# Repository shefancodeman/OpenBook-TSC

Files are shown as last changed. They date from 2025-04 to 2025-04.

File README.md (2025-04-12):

# TSC Openbook
 Un eBook reader format din PCB, carcasa, baterie si display, creat in AutoDesk Fusion. Fiecare component e asezat pe pcb pentru a intra corespunzator in carcasa.  
PCB-ul include:
- Battery Charge Level  
- E-Paper Display Header  
- E-Paper Drive Circuit  
- Environmental Sensor BME688  
- EPD Power  
- ESP32 C6  
- External NOR Flash 64MB  
- LDO Voltage Regulator  
- Li-Po Battery Charging Controller  
- Qwiic / Stemma QT  
- RTC Module DS3231SN  
- SD Card  
- SPI ESD Protection Lines  
- Test Pads  
- USB C connector & ESD protection  
- Voltage Supervisor + Reset & Boot / IO Button  

## BOM
| Component | Websites | Datasheet |
|---|---|---|
| ESP32-C6-WROOM-1-N8 | [Mouser](https://eu.mouser.com/ProductDetail/Espressif-Systems/ESP32-C6-WROOM-1U-N8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) | [Datasheet](https://eu.mouser.com/datasheet/2/891/Espressif_Systems_7_11_2023_esp32_c6_wroom_1_wroom-3236277.pdf) |
| USB4110-GF-A | [Mouser](https://eu.mouser.com/ProductDetail/Same-Sky/UJC-H-G-SMT-2-P6-TR?qs=IKkN%2F947nfApFV8T6rOqww%3D%3D) | [Datasheet](https://eu.mouser.com/datasheet/2/1628/ujc_h_g_smt_2_p6_tr-3511211.pdf) |
| USBLC6-2SC6Y | [Mouser](https://eu.mouser.com/ProductDetail/STMicroelectronics/USBLC6-2SC6Y?qs=gNDSiZmRJS%2FOgDexvXkdow%3D%3D) | [Datasheet](https://eu.mouser.com/datasheet/2/389/usblc6_2sc6y-1852505.pdf) |
| DMG2305UX-7 | [Mouser](https://eu.mouser.com/ProductDetail/Diodes-Incorporated/DMG2305UX-7?qs=L1DZKBg7t5F%2FNBHrjfxC%252Bg%3D%3D) | [Datasheet](https://www.diodes.com/assets/Datasheets/DMG2305UX.pdf) |
| SD0805S020S1R0 | [Mouser](https://eu.mouser.com/ProductDetail/KYOCERA-AVX/SD0805S020S1R0?qs=jCA%252BPfw4LHbpkAoSnwrdjw%3D%3D) | [Datasheet](https://eu.mouser.com/datasheet/2/40/schottky-3165252.pdf) |
| XC6220A331MR-G | [Mouser](https://eu.mouser.com/ProductDetail/Torex-Semiconductor/XC6220A331MR-G?qs=AsjdqWjXhJ8ZSWznL1J0gg%3D%3D) | [Datasheet](https://eu.mouser.com/datasheet/2/760/xc6220-3371556.pdf) |
| 293D107X9010D2TE3 | [Mouser](https://eu.mouser.com/ProductDetail/Vishay-Sprague/293D107X9010D2TE3?qs=8dfOI6wKXonVqFgS8%252BQ%2FMA%3D%3D) | [Datasheet](https://www.vishay.com/docs/40002/293d.pdf) |
| IFDC5050JZER680M | [Mouser](https://eu.mouser.com/ProductDetail/Vishay-Dale/IFDC5050JZER680M?qs=iLKYxzqNS745SePZd8tBoA%3D%3D) | [Datasheet](https://www.vishay.com/docs/34635/ifdc5050jz.pdf) |
| MBR0530-TP | [Mouser](https://eu.mouser.com/ProductDetail/Micro-Commercial-Components-MCC/MBR0530-TP?qs=KFo7JewZbUECRHkxGanrdg%3D%3D) | [Datasheet](https://eu.mouser.com/datasheet/2/258/MBR0520_MBR0580_SOD123_-2492194.pdf) |
| SI1308EDL-T1-GE3 | [Mouser](https://eu.mouser.com/ProductDetail/Vishay-Semiconductors/SI1308EDL-T1-GE3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) | [Datasheet](https://www.vishay.com/docs/63399/si1308edl.pdf) |
| KGF21BR71H104KT | [Mouser](https://eu.mouser.com/ProductDetail/KYOCERA-AVX/KGF21BR71H104KT?qs=Jm2GQyTW%2FbjYyKCvVWAEOw%3D%3D) | [Datasheet](https://eu.mouser.com/datasheet/2/40/KGF-3223650.pdf) |
| MAASL105CC7105MFCA01 | [Mouser](https://eu.mouser.com/ProductDetail/TAIYO-YUDEN/MAASL105CC7105MFCA01?qs=HFfMDpzxxd1Fn%2FInbJA7vw%3D%3D) | [Datasheet](https://eu.mouser.com/datasheet/2/396/TAIYO_YUDEN_04_27_2024_c_mlcc_A_e1-3451516.pdf) |
| CM05X5R475M16AH | [Mouser](https://eu.mouser.com/ProductDetail/KYOCERA-AVX/CM05X5R475M16AH?qs=doiCPypUmgFT1xquZKhWtQ%3D%3D) | [Datasheet](https://eu.mouser.com/datasheet/2/40/Kyocera_AVX_Components_CM025_CM05_CM105_CM21_E217K-2932876.pdf) |
| CGA3EDX7T1A106M080AU | [Mouser](https://eu.mouser.com/ProductDetail/TDK/CGA3EDX7T1A106M080AU?qs=ZcfC38r4PovL%2FBNBUzzBFw%3D%3D) | [Datasheet](https://product.tdk.com/system/files/dam/doc/product/capacitor/ceramic/mlcc/catalog/mlcc_automotive_general_en.pdf) |
| KAM21BR71H104JT | [Mouser](https://eu.mouser.com/ProductDetail/KYOCERA-AVX/KAM21BR71H104JT?qs=Jm2GQyTW%2Fbic6Zk4McEt6w%3D%3D) | [Datasheet](https://eu.mouser.com/datasheet/2/40/AutoMLCCKAM-3216307.pdf) |
| RNCL1210FT50L0 | [Mouser](https://eu.mouser.com/ProductDetail/SEI-Stackpole/RNCL1210FT50L0?qs=17ckDYBRdelVLOJ%252BDFjlUw%3D%3D) | [Datasheet](https://eu.mouser.com/datasheet/2/385/sei_rncl-3223524.pdf) |
| RT1206FRE072R2L | [Mouser](https://eu.mouser.com/ProductDetail/YAGEO/RT1206FRE072R2L?qs=XhSZopxZ3H6S0nYZD83pAA%3D%3D) | [Datasheet](https://eu.mouser.com/datasheet/2/447/PYu_RT_1_to_0_01_RoHS_L_15-3461507.pdf) |
| ERA-6AHD150V | [Mouser](https://eu.mouser.com/ProductDetail/Panasonic/ERA-6AHD150V?qs=MNPzkKEzRtQip8ZeekU%252BRw%3D%3D) | [Datasheet](https://industrial.panasonic.com/cdbs/www-data/pdf/RDM0000/AOA0000C307.pdf) |
| RP73C2B200RFTDF | [Mouser](https://eu.mouser.com/ProductDetail/TE-Connectivity-Holsworthy/RP73C2B200RFTDF?qs=n4i9pByFsMR0dWGpf721CA%3D%3D) | [Datasheet](https://eu.mouser.com/datasheet/2/418/10/ENG_DS_1773272_M1-1588495.pdf) |
| ERA-3AED202V | [Mouser](https://eu.mouser.com/ProductDetail/Panasonic/ERA-3AED202V?qs=yocZuyCaXdM2cBmjcGkIyA%3D%3D) | [Datasheet](https://industrial.panasonic.com/cdbs/www-data/pdf/RDM0000/AOA0000C307.pdf) |
| MCS04020C5101FE000 | [Mouser](https://eu.mouser.com/ProductDetail/Vishay-Beyschlag/MCS04020C5101FE000?qs=wTZ%2FFzl837YsKPLPRIXUbg%3D%3D) | [Datasheet](https://www.vishay.com/docs/28705/mcx0x0xpro.pdf) |
| RNWA0612BTE10K0 | [Mouser](https://eu.mouser.com/ProductDetail/SEI-Stackpole/RNWA0612BTE10K0?qs=IKkN%2F947nfD62pDKWE9ZTQ%3D%3D) | [Datasheet](https://eu.mouser.com/datasheet/2/385/SEI_RNWA-3473840.pdf) |
| ERA-3AED104V | [Mouser](https://eu.mouser.com/ProductDetail/Panasonic/ERA-3AED104V?qs=MNPzkKEzRtQIWcmUWL4kjg%3D%3D) | [Datasheet](https://industrial.panasonic.com/cdbs/www-data/pdf/RDM0000/AOA0000C307.pdf) |
| MCP73831-2ACI-MC | [Mouser](https://eu.mouser.com/ProductDetail/Microchip-Technology/MCP73831-2ACI-MC?qs=hH%252BOa0VZEiBneYTVdpuVdg%3D%3D) | [Datasheet](https://eu.mouser.com/datasheet/2/268/MCP73831_Family_Data_Sheet_DS20001984H-3441711.pdf) |
| FH34SRJ-24S-0.5SH(99) | [Mouser](https://eu.mouser.com/ProductDetail/Hirose-Connector/FH34SRJ-24S-0.5SH99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) | [Datasheet](https://eu.mouser.com/datasheet/2/185/FH34SRJ_24S_0_5SH_99__CL0580_1255_6_99_2DDrawing_0-1615044.pdf) |
| BME688 | [Mouser](https://eu.mouser.com/ProductDetail/Bosch-Sensortec/BME688?qs=IS%252B4QmGtzzqQoVDscqwx3A%3D%3D) | [Datasheet](https://eu.mouser.com/datasheet/2/783/bst_bme688_fl000-2307034.pdf) |
| BD5229G-TR | [Mouser](https://eu.mouser.com/ProductDetail/ROHM-Semiconductor/BD5229G-TR?qs=4kLU8WoGk0vvnhrrYwdszw%3D%3D) | [Datasheet](https://fscdn.rohm.com/en/products/databook/datasheet/ic/power/voltage_detector/bd52xxg-e.pdf)  |
| MAX17048G+T10 | [Mouser](https://eu.mouser.com/ProductDetail/Analog-Devices-Maxim-Integrated/MAX17048G%2bT10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) | [Datasheet](https://eu.mouser.com/datasheet/2/609/MAX17048_MAX17049-3469099.pdf) |
| DS3231SN# | [Mouser](https://eu.mouser.com/ProductDetail/Analog-Devices-Maxim-Integrated/DS3231SN?qs=1eQvB6Dk1vhUlr8%2FOrV0Fw%3D%3D) | [Datasheet](https://eu.mouser.com/datasheet/2/609/DS3231-3421123.pdf) |
| CPH3225A | [Mouser](https://eu.mouser.com/ProductDetail/Seiko-Semiconductors/CPH3225A?qs=3etwrb1wR%252BhUOph6lAO7eg%3D%3D) | [Datasheet](https://eu.mouser.com/datasheet/2/360/Seiko_Instruments_MicroBattery_E_20230330_2024Jan_-3561061.pdf) |
| PRT-14417 | [Mouser](https://eu.mouser.com/ProductDetail/Adafruit/4208?qs=PzGy0jfpSMtbScLbr0L5dw%3D%3D) | [Datasheet](https://learn.adafruit.com/introducing-adafruit-stemma-qt/technical-specs) |
| PGB1010603MR | [Mouser](https://eu.mouser.com/ProductDetail/Littelfuse/PGB1010603MR?qs=gu7KAQ731URLg4GSnNNN7Q%3D%3D) | [Datasheet](https://www.littelfuse.com/assetdocs/pulseguard-esd-suppressors-pgb1-datasheet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) |
| W25Q512JVEIQ | [Mouser](https://eu.mouser.com/ProductDetail/Winbond/W25Q512JVEIQ?qs=l7cgNqFNU1jw6svr3at6tA%3D%3D) | [Datasheet](https://eu.mouser.com/datasheet/2/949/Winbond_W25Q512JV_Datasheet-3240039.pdf) |
| MT-DEPG0750BNU590F1 | [Mouser](https://eu.mouser.com/ProductDetail/Microtips-Technology/MT-DEPG0750BNU590F1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) | [Datasheet](https://eu.mouser.com/datasheet/2/271/MT_DEPG0750BNU590F1_V2_7-1894282.pdf) |
| 112A-TAAR-R03 | [Comet](https://store.comet.srl.ro/Catalogue/Product/43497/) | [Datasheet](https://store.comet.bg/download-file.php?id=27596) |
| LP584174 | [TME](https://www.tme.eu/en/details/accu-lp584174_cl/rechargeable-batteries/cellevia-batteries/l584174/) | [Datasheet](https://www.tme.eu/Document/e0683d8c34e6d878124489f71bffb6ee/cel0014.pdf) |

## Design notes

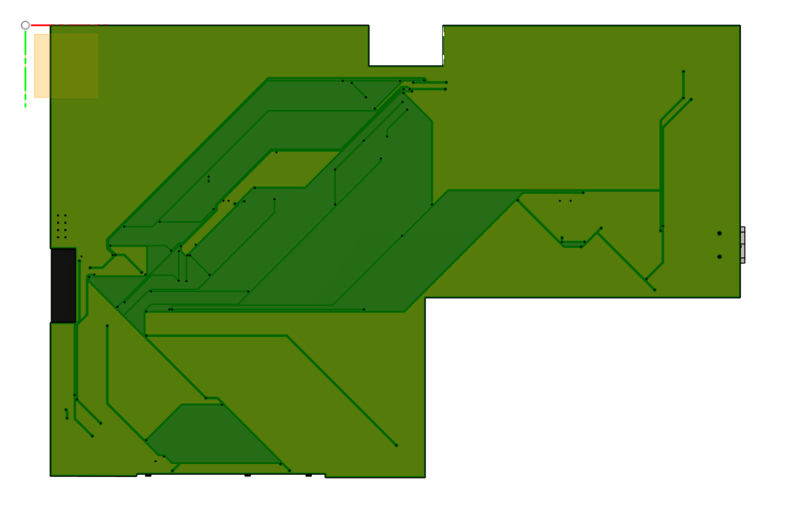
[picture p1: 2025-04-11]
Images/pcb_bottom.png

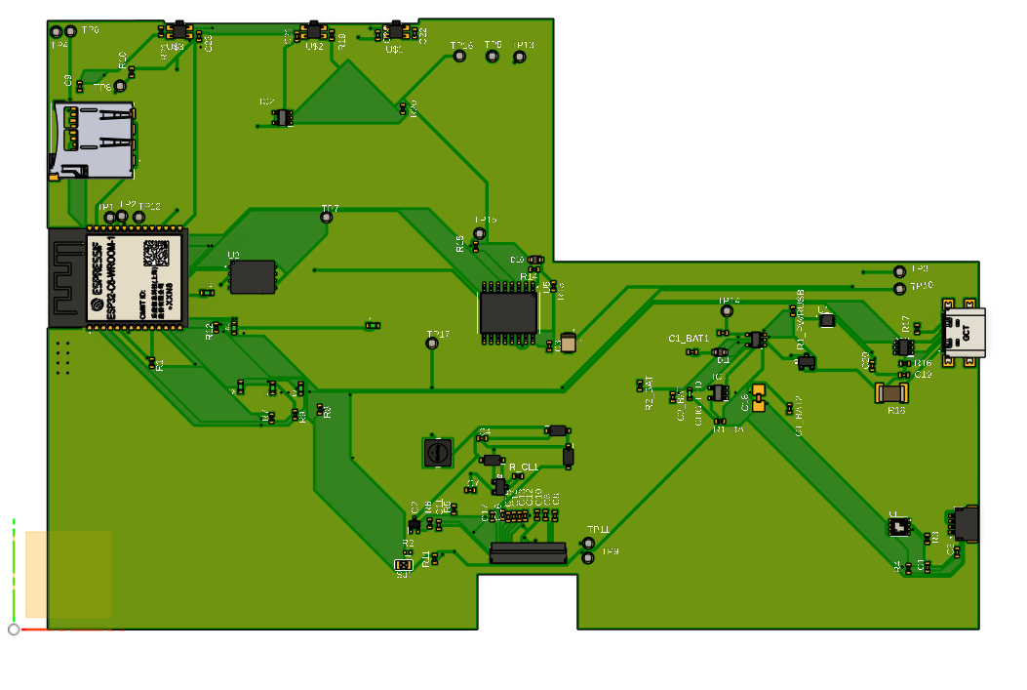
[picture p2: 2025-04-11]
Images/pcb_top.png

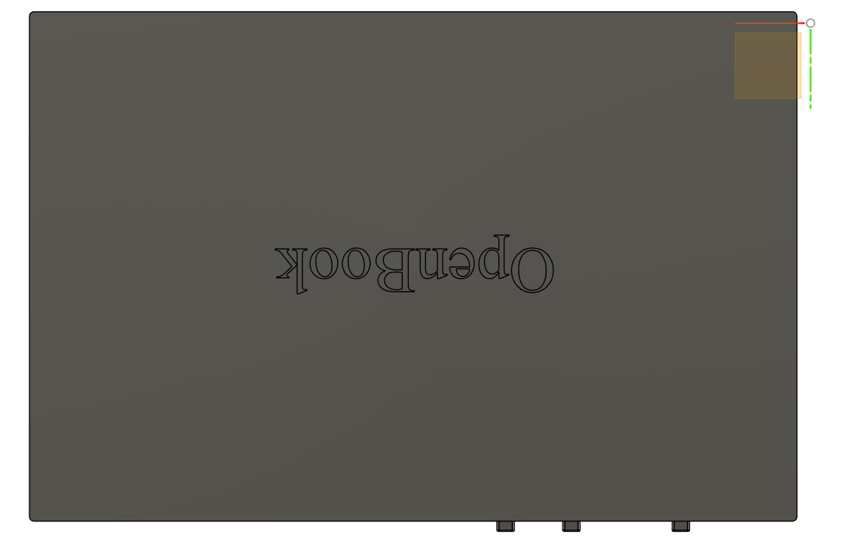
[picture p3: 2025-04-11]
Images/ebook_bot.png

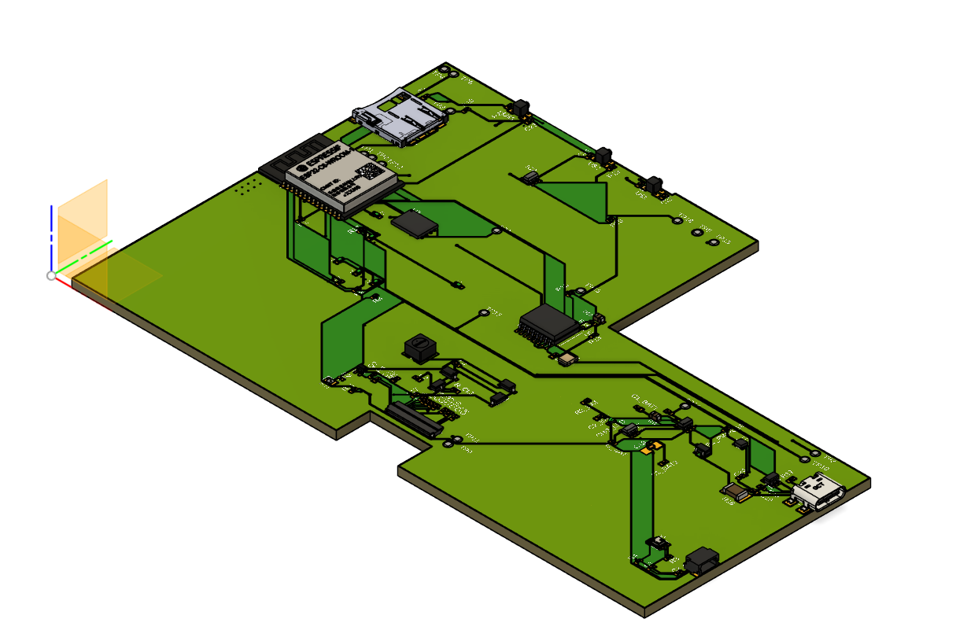
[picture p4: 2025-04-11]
Images/pcb_view.png

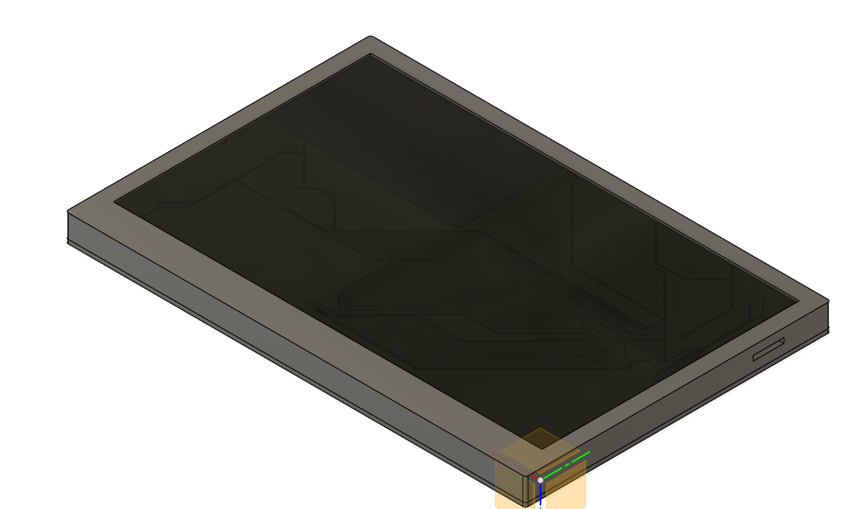
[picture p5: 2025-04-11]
Images/ebook_view.png

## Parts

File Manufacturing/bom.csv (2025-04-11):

Part | Value | Device | Package | Description | ARROW_PART_NUMBER | ARROW_PRICE-STOCK | AVAILABILITY | CATEGORY | CENTROID_NOT_SPECIFIED | CHECK_PRICES | COPYRIGHT | DATASHEET | DESCRIPTION | DIGIKEY_DESCRIPTION | DIGIKEY_PART_NUMBER | HEIGHT | LEAD_FREE | MANUFACTURER | MANUFACTURER_NAME | MANUFACTURER_PART_NUMBER | MF | MFR_NAME | MOUSER_PART_NUMBER | MOUSER_PRICE-STOCK | MOUSER_TESTING_PART_NUMBER | MOUSER_TESTING_PRICE-STOCK | MP | MPN | OPERATING_TEMPERATURE | PACKAGE | PACKAGE_SIZE | PACKAGE_TYPE | PART_STATUS | POPULARITY | PREFIX | PRICE | PROD_ID | PURCHASE-URL | ROHS | SERIES | SNAPEDA_LINK | SPICEMODEL | SPICEPREFIX | SUBCATEGORY | TEMPERATURE_COEFFICIENT | TEMPERATURE_RANGE_HIGH | TEMPERATURE_RANGE_LOW | THERMALLOSS | TOLERANCE | TP_SIGNAL_NAME | TYPE | VALUE
C1 |  | ESP32_WROVER_EAGLE-LTSPICE_CC0402 | ESP32_WROVER_EAGLE-LTSPICE_C0402 | CAPACITOR, European symbol |  |  |  |  |  |  |  |  |  |  |  |  |  |  |  |  |  |  |  |  |  |  |  |  |  |  |  |  |  |  |  |  |  |  |  |  |  | NONE | C
C1_BAT | 4.7uF | ESP32_WROVER_EAGLE-LTSPICE_CC0402 | ESP32_WROVER_EAGLE-LTSPICE_C0402 | CAPACITOR, European symbol |  |  |  |  |  |  |  |  |  |  |  |  |  |  |  |  |  |  |  |  |  |  |  |  |  |  |  |  |  |  |  |  |  |  |  |  |  | NONE | C
C1_BAT1 | 4.7uF | ESP32_WROVER_EAGLE-LTSPICE_CC0402 | ESP32_WROVER_EAGLE-LTSPICE_C0402 | CAPACITOR, European symbol |  |  |  |  |  |  |  |  |  |  |  |  |  |  |  |  |  |  |  |  |  |  |  |  |  |  |  |  |  |  |  |  |  |  |  |  |  | NONE | C
C1_BAT2 | 4.7uF | ESP32_WROVER_EAGLE-LTSPICE_CC0402 | ESP32_WROVER_EAGLE-LTSPICE_C0402 | CAPACITOR, European symbol |  |  |  |  |  |  |  |  |  |  |  |  |  |  |  |  |  |  |  |  |  |  |  |  |  |  |  |  |  |  |  |  |  |  |  |  |  | NONE | C
C2 |  | ESP32_WROVER_EAGLE-LTSPICE_CC0402 | ESP32_WROVER_EAGLE-LTSPICE_C0402 | CAPACITOR, European symbol |  |  |  |  |  |  |  |  |  |  |  |  |  |  |  |  |  |  |  |  |  |  |  |  |  |  |  |  |  |  |  |  |  |  |  |  |  | NONE | C
C2_BAT | 4.7uF | ESP32_WROVER_EAGLE-LTSPICE_CC0402 | ESP32_WROVER_EAGLE-LTSPICE_C0402 | CAPACITOR, European symbol |  |  |  |  |  |  |  |  |  |  |  |  |  |  |  |  |  |  |  |  |  |  |  |  |  |  |  |  |  |  |  |  |  |  |  |  |  | NONE | C
C3 |  | EAGLE-LTSPICE_CC0402 | EAGLE-LTSPICE_C0402 | CAPACITOR, European symbol |  |  |  |  |  |  |  |  |  |  |  |  |  |  |  |  |  |  |  |  |  |  |  |  |  |  |  |  |  |  |  |  |  |  |  |  |  | NONE | C
C4 | 4.7uF/25V | EAGLE-LTSPICE_CC0402 | EAGLE-LTSPICE_C0402 | CAPACITOR, European symbol |  |  |  |  |  |  |  |  |  |  |  |  |  |  |  |  |  |  |  |  |  |  |  |  |  |  |  |  |  |  |  |  |  |  |  |  |  | NONE | C
C5 | CPH3225A | CPH3225A | CAPCP3225X100N | Cap 0.011F 3.3V 1210 Flat Check availability |  |  | Not in stock |  |  | https://www.snapeda.com/parts/CPH3225A/Seiko+Instruments/view-part/?ref=eda |  |  | 11 mF (EDLC) Supercapacitor 3.3 V 1210 (3225 Metric) - - |  |  |  |  |  |  |  | Seiko Instruments |  |  |  |  |  | CPH3225A |  |  | 1210 Seiko |  |  |  |  |  | None |  | https://www.snapeda.com/api/url_track_click_mouser/?unipart_id=562593&manufacturer=Seiko Instruments&part_name=CPH3225A&search_term=None |  |  | https://www.snapeda.com/parts/CPH3225A/Seiko+Instruments/view-part/?ref=snap
C6 | 1uF/50V | ESP32_WROVER_EAGLE-LTSPICE_CC0402 | ESP32_WROVER_EAGLE-LTSPICE_C0402 | CAPACITOR, European symbol |  |  |  |  |  |  |  |  |  |  |  |  |  |  |  |  |  |  |  |  |  |  |  |  |  |  |  |  |  |  |  |  |  |  |  |  |  | NONE | C
C7 | 10uF | EAGLE-LTSPICE_CC0402 | EAGLE-LTSPICE_C0402 | CAPACITOR, European symbol |  |  |  |  |  |  |  |  |  |  |  |  |  |  |  |  |  |  |  |  |  |  |  |  |  |  |  |  |  |  |  |  |  |  |  |  |  | NONE | C
C8 | 1uF/50V | ESP32_WROVER_EAGLE-LTSPICE_CC0402 | ESP32_WROVER_EAGLE-LTSPICE_C0402 | CAPACITOR, European symbol |  |  |  |  |  |  |  |  |  |  |  |  |  |  |  |  |  |  |  |  |  |  |  |  |  |  |  |  |  |  |  |  |  |  |  |  |  | NONE | C
C9 | 100nF | EAGLE-LTSPICE_CC0402 | EAGLE-LTSPICE_C0402 | CAPACITOR, European symbol |  |  |  |  |  |  |  |  |  |  |  |  |  |  |  |  |  |  |  |  |  |  |  |  |  |  |  |  |  |  |  |  |  |  |  |  |  | NONE | C
C10 | 0.1uF/50V | ESP32_WROVER_EAGLE-LTSPICE_CC0402 | ESP32_WROVER_EAGLE-LTSPICE_C0402 | CAPACITOR, European symbol |  |  |  |  |  |  |  |  |  |  |  |  |  |  |  |  |  |  |  |  |  |  |  |  |  |  |  |  |  |  |  |  |  |  |  |  |  | NONE | C
C11 | 1uF/50V | ESP32_WROVER_EAGLE-LTSPICE_CC0402 | ESP32_WROVER_EAGLE-LTSPICE_C0402 | CAPACITOR, European symbol |  |  |  |  |  |  |  |  |  |  |  |  |  |  |  |  |  |  |  |  |  |  |  |  |  |  |  |  |  |  |  |  |  |  |  |  |  | NONE | C
C12 | 1uF/50V | ESP32_WROVER_EAGLE-LTSPICE_CC0402 | ESP32_WROVER_EAGLE-LTSPICE_C0402 | CAPACITOR, European symbol |  |  |  |  |  |  |  |  |  |  |  |  |  |  |  |  |  |  |  |  |  |  |  |  |  |  |  |  |  |  |  |  |  |  |  |  |  | NONE | C
C13 | 1uF/50V | ESP32_WROVER_EAGLE-LTSPICE_CC0402 | ESP32_WROVER_EAGLE-LTSPICE_C0402 | CAPACITOR, European symbol |  |  |  |  |  |  |  |  |  |  |  |  |  |  |  |  |  |  |  |  |  |  |  |  |  |  |  |  |  |  |  |  |  |  |  |  |  | NONE | C
C14 | 1uF/50V | ESP32_WROVER_EAGLE-LTSPICE_CC0402 | ESP32_WROVER_EAGLE-LTSPICE_C0402 | CAPACITOR, European symbol |  |  |  |  |  |  |  |  |  |  |  |  |  |  |  |  |  |  |  |  |  |  |  |  |  |  |  |  |  |  |  |  |  |  |  |  |  | NONE | C
C15 | 1uF/50V | ESP32_WROVER_EAGLE-LTSPICE_CC0402 | ESP32_WROVER_EAGLE-LTSPICE_C0402 | CAPACITOR, European symbol |  |  |  |  |  |  |  |  |  |  |  |  |  |  |  |  |  |  |  |  |  |  |  |  |  |  |  |  |  |  |  |  |  |  |  |  |  | NONE | C
C16 | 1uF/50V | ESP32_WROVER_EAGLE-LTSPICE_CC0402 | ESP32_WROVER_EAGLE-LTSPICE_C0402 | CAPACITOR, European symbol |  |  |  |  |  |  |  |  |  |  |  |  |  |  |  |  |  |  |  |  |  |  |  |  |  |  |  |  |  |  |  |  |  |  |  |  |  | NONE | C
C17 | 1uF/50V | ESP32_WROVER_EAGLE-LTSPICE_CC0402 | ESP32_WROVER_EAGLE-LTSPICE_C0402 | CAPACITOR, European symbol |  |  |  |  |  |  |  |  |  |  |  |  |  |  |  |  |  |  |  |  |  |  |  |  |  |  |  |  |  |  |  |  |  |  |  |  |  | NONE | C
C18 | 100uF | RCL_CPOL-EUCT3528 | RCL_CT3528 | POLARIZED CAPACITOR, European symbol |  |  |  |  |  |  |  |  |  |  |  |  |  |  |  |  |  |  |  |  |  |  |  |  |  |  |  |  |  | 0 |  |  |  |  |  |  |  |  | C
C19 | 100nF | ESP32_WROVER_EAGLE-LTSPICE_CC0402 | ESP32_WROVER_EAGLE-LTSPICE_C0402 | CAPACITOR, European symbol |  |  |  |  |  |  |  |  |  |  |  |  |  |  |  |  |  |  |  |  |  |  |  |  |  |  |  |  |  |  |  |  |  |  |  |  |  | NONE | C
C20 | 4.7uF | ESP32_WROVER_EAGLE-LTSPICE_CC0402 | ESP32_WROVER_EAGLE-LTSPICE_C0402 | CAPACITOR, European symbol |  |  |  |  |  |  |  |  |  |  |  |  |  |  |  |  |  |  |  |  |  |  |  |  |  |  |  |  |  |  |  |  |  |  |  |  |  | NONE | C
C21 | 100nF | ESP32_WROVER_EAGLE-LTSPICE_CC0402 | ESP32_WROVER_EAGLE-LTSPICE_C0402 | CAPACITOR, European symbol |  |  |  |  |  |  |  |  |  |  |  |  |  |  |  |  |  |  |  |  |  |  |  |  |  |  |  |  |  |  |  |  |  |  |  |  |  | NONE | C
C22 | 1uF | ESP32_WROVER_EAGLE-LTSPICE_CC0402 | ESP32_WROVER_EAGLE-LTSPICE_C0402 | CAPACITOR, European symbol |  |  |  |  |  |  |  |  |  |  |  |  |  |  |  |  |  |  |  |  |  |  |  |  |  |  |  |  |  |  |  |  |  |  |  |  |  | NONE | C
C23 | 100nF | ESP32_WROVER_EAGLE-LTSPICE_CC0402 | ESP32_WROVER_EAGLE-LTSPICE_C0402 | CAPACITOR, European symbol |  |  |  |  |  |  |  |  |  |  |  |  |  |  |  |  |  |  |  |  |  |  |  |  |  |  |  |  |  |  |  |  |  |  |  |  |  | NONE | C
C24 | 100nF | ESP32_WROVER_EAGLE-LTSPICE_CC0402 | ESP32_WROVER_EAGLE-LTSPICE_C0402 | CAPACITOR, European symbol |  |  |  |  |  |  |  |  |  |  |  |  |  |  |  |  |  |  |  |  |  |  |  |  |  |  |  |  |  |  |  |  |  |  |  |  |  | NONE | C
CHG_LED |  | ADAFRUIT_LEDCHIP-LED0603 | ADAFRUIT_CHIP-LED0603 | LED
D1 | MBR0530 | MBR0530 | SOD3716X135N | ON SEMICONDUCTOR - MBR0530 - DIODE, SCHOTTKY, 0.5A, 30V, SOD-123 |  |  | In Stock |  |  | https://www.snapeda.com/parts/MBR0530/Onsemi/view-part/?ref=eda |  |  | Diode Schottky 30 V 500mA Surface Mount SOD-123 |  |  |  |  |  |  |  | ON Semiconductor |  |  |  |  |  | MBR0530 |  |  | SOD-123-2 ON Semiconductor |  |  |  |  |  | None |  | https://www.snapeda.com/api/url_track_click_mouser/?unipart_id=179458&manufacturer=ON Semiconductor&part_name=MBR0530&search_term=None |  |  | https://www.snapeda.com/parts/MBR0530/Onsemi/view-part/?ref=snap
D2 | MBR0530 | MBR0530 | SOD3716X135N | ON SEMICONDUCTOR - MBR0530 - DIODE, SCHOTTKY, 0.5A, 30V, SOD-123 |  |  | In Stock |  |  | https://www.snapeda.com/parts/MBR0530/Onsemi/view-part/?ref=eda |  |  | Diode Schottky 30 V 500mA Surface Mount SOD-123 |  |  |  |  |  |  |  | ON Semiconductor |  |  |  |  |  | MBR0530 |  |  | SOD-123-2 ON Semiconductor |  |  |  |  |  | None |  | https://www.snapeda.com/api/url_track_click_mouser/?unipart_id=179458&manufacturer=ON Semiconductor&part_name=MBR0530&search_term=None |  |  | https://www.snapeda.com/parts/MBR0530/Onsemi/view-part/?ref=snap
D3 | MBR0530 | MBR0530 | SOD3716X135N | ON SEMICONDUCTOR - MBR0530 - DIODE, SCHOTTKY, 0.5A, 30V, SOD-123 |  |  | In Stock |  |  | https://www.snapeda.com/parts/MBR0530/Onsemi/view-part/?ref=eda |  |  | Diode Schottky 30 V 500mA Surface Mount SOD-123 |  |  |  |  |  |  |  | ON Semiconductor |  |  |  |  |  | MBR0530 |  |  | SOD-123-2 ON Semiconductor |  |  |  |  |  | None |  | https://www.snapeda.com/api/url_track_click_mouser/?unipart_id=179458&manufacturer=ON Semiconductor&part_name=MBR0530&search_term=None |  |  | https://www.snapeda.com/parts/MBR0530/Onsemi/view-part/?ref=snap
D4 | PGB1010603MR | PGB1010603MR | DIOC1608X36N | Check availability |  |  | In Stock |  |  | https://www.snapeda.com/parts/PGB1010603MR/Littelfuse/view-part/?ref=eda |  |  | 150V (Typ) Clamp - Ipp Tvs Diode Surface Mount 0603 (1608 Metric) |  |  |  |  |  |  |  | Littelfuse Inc. |  |  |  |  |  | PGB1010603MR |  |  | 0603 Littelfuse Inc. |  |  |  |  |  | None |  | https://www.snapeda.com/api/url_track_click_mouser/?unipart_id=5659453&manufacturer=Littelfuse Inc.&part_name=PGB1010603MR&search_term=None |  |  | https://www.snapeda.com/parts/PGB1010603MR/Littelfuse/view-part/?ref=snap
D5 | PGB1010603MR | PGB1010603MR | DIOC1608X36N | Check availability |  |  | In Stock |  |  | https://www.snapeda.com/parts/PGB1010603MR/Littelfuse/view-part/?ref=eda |  |  | 150V (Typ) Clamp - Ipp Tvs Diode Surface Mount 0603 (1608 Metric) |  |  |  |  |  |  |  | Littelfuse Inc. |  |  |  |  |  | PGB1010603MR |  |  | 0603 Littelfuse Inc. |  |  |  |  |  | None |  | https://www.snapeda.com/api/url_track_click_mouser/?unipart_id=5659453&manufacturer=Littelfuse Inc.&part_name=PGB1010603MR&search_term=None |  |  | https://www.snapeda.com/parts/PGB1010603MR/Littelfuse/view-part/?ref=snap
D6 | PGB1010603MR | PGB1010603MR | DIOC1608X36N | Check availability |  |  | In Stock |  |  | https://www.snapeda.com/parts/PGB1010603MR/Littelfuse/view-part/?ref=eda |  |  | 150V (Typ) Clamp - Ipp Tvs Diode Surface Mount 0603 (1608 Metric) |  |  |  |  |  |  |  | Littelfuse Inc. |  |  |  |  |  | PGB1010603MR |  |  | 0603 Littelfuse Inc. |  |  |  |  |  | None |  | https://www.snapeda.com/api/url_track_click_mouser/?unipart_id=5659453&manufacturer=Littelfuse Inc.&part_name=PGB1010603MR&search_term=None |  |  | https://www.snapeda.com/parts/PGB1010603MR/Littelfuse/view-part/?ref=snap
D7 | PGB1010603MR | PGB1010603MR | DIOC1608X36N | Check availability |  |  | In Stock |  |  | https://www.snapeda.com/parts/PGB1010603MR/Littelfuse/view-part/?ref=eda |  |  | 150V (Typ) Clamp - Ipp Tvs Diode Surface Mount 0603 (1608 Metric) |  |  |  |  |  |  |  | Littelfuse Inc. |  |  |  |  |  | PGB1010603MR |  |  | 0603 Littelfuse Inc. |  |  |  |  |  | None |  | https://www.snapeda.com/api/url_track_click_mouser/?unipart_id=5659453&manufacturer=Littelfuse Inc.&part_name=PGB1010603MR&search_term=None |  |  | https://www.snapeda.com/parts/PGB1010603MR/Littelfuse/view-part/?ref=snap
D8 | PGB1010603MR | PGB1010603MR | DIOC1608X36N | Check availability |  |  | In Stock |  |  | https://www.snapeda.com/parts/PGB1010603MR/Littelfuse/view-part/?ref=eda |  |  | 150V (Typ) Clamp - Ipp Tvs Diode Surface Mount 0603 (1608 Metric) |  |  |  |  |  |  |  | Littelfuse Inc. |  |  |  |  |  | PGB1010603MR |  |  | 0603 Littelfuse Inc. |  |  |  |  |  | None |  | https://www.snapeda.com/api/url_track_click_mouser/?unipart_id=5659453&manufacturer=Littelfuse Inc.&part_name=PGB1010603MR&search_term=None |  |  | https://www.snapeda.com/parts/PGB1010603MR/Littelfuse/view-part/?ref=snap
D9 | PGB1010603MR | PGB1010603MR | DIOC1608X36N | Check availability |  |  | In Stock |  |  | https://www.snapeda.com/parts/PGB1010603MR/Littelfuse/view-part/?ref=eda |  |  | 150V (Typ) Clamp - Ipp Tvs Diode Surface Mount 0603 (1608 Metric) |  |  |  |  |  |  |  | Littelfuse Inc. |  |  |  |  |  | PGB1010603MR |  |  | 0603 Littelfuse Inc. |  |  |  |  |  | None |  | https://www.snapeda.com/api/url_track_click_mouser/?unipart_id=5659453&manufacturer=Littelfuse Inc.&part_name=PGB1010603MR&search_term=None |  |  | https://www.snapeda.com/parts/PGB1010603MR/Littelfuse/view-part/?ref=snap
D10 | ESP32_WROVER_AVX---SD0805S020S1R0_AVX_SD0805S020S1R0_0_0AVX_SD0805S020S1R0_0_0 | ESP32_WROVER_AVX---SD0805S020S1R0_AVX_SD0805S020S1R0_0_0AVX_SD0805S020S1R0_0_0 | ESP32_WROVER_AVX---SD0805S020S1R0_AVX_SD0805S020S1R0_0 | Schottky Barrier Rectifier Diode |  |  |  |  | No |  |  | http://datasheets.avx.com/schottky.pdf |  | DIODE SCHOTTKY 20V 1A 0805 | 478-7800-1-ND |  | yes |  |  |  | AVX |  | 581-SD0805S020S1R0 |  |  |  |  |  |  | 0805 (2012 metric) |  |  |  |  | D |  |  |  | yes |  |  |  |  |  |  | +125°C | -55°C
D11 | ESP32_WROVER_AVX---SD0805S020S1R0_AVX_SD0805S020S1R0_0_0AVX_SD0805S020S1R0_0_0 | ESP32_WROVER_AVX---SD0805S020S1R0_AVX_SD0805S020S1R0_0_0AVX_SD0805S020S1R0_0_0 | ESP32_WROVER_AVX---SD0805S020S1R0_AVX_SD0805S020S1R0_0 | Schottky Barrier Rectifier Diode |  |  |  |  | No |  |  | http://datasheets.avx.com/schottky.pdf |  | DIODE SCHOTTKY 20V 1A 0805 | 478-7800-1-ND |  | yes |  |  |  | AVX |  | 581-SD0805S020S1R0 |  |  |  |  |  |  | 0805 (2012 metric) |  |  |  |  | D |  |  |  | yes |  |  |  |  |  |  | +125°C | -55°C
D12 | USBLC6-2SC6Y | USBLC6-2SC6Y | SOT95P280X145-6N | Low Cap. ESD Protection Auto SOT-23-6 STMicroelectronics USBLC6-2SC6Y, Dual Uni-Directional TVS Diode Array, 6-Pin SOT-23 |  |  | In Stock |  |  | https://www.snapeda.com/parts/USBLC6-2SC6Y/STMicroelectronics/view-part/?ref=eda |  |  | 17V Clamp 5A (8/20µs) Ipp Tvs Diode Surface Mount SOT-23-6 |  |  |  |  |  |  |  | STMicroelectronics |  |  |  |  |  | USBLC6-2SC6Y |  |  | SOT-23-6 STMicroelectronics |  |  |  |  |  | None |  |  |  |  | https://www.snapeda.com/parts/USBLC6-2SC6Y/STMicroelectronics/view-part/?ref=snap
IC1 | XC6220A331MR-G | XC6220A331MR-G | SOT95P280X120-5N | LDO Voltage Regulators |  |  |  |  |  |  |  |  | LDO Voltage Regulators |  |  | 1.2mm |  |  | Torex | XC6220A331MR-G |  |  | 865-XC6220A331MR-G | https://www.mouser.co.uk/ProductDetail/Torex-Semiconductor/XC6220A331MR-G?qs=AsjdqWjXhJ8ZSWznL1J0gg%3D%3D
IC2 | BD5229G-TR | BD5229G-TR | SOT95P280X125-5N | Voltage Detector with Adjustable Delay Time: CMOS processes are utilized to develop high precision, low current consumption CMOS reset ICs that allow arbitrary setting of the delay time. The extensive lineup includes both Nch Open Drain and CMOS output types in a wide range of detection voltages (from 2.3V to 6.0V, in 0.1V steps), enabling selection of the ideal solution based on customer requirements. In addition, the entire series is of course both lead-free and RoHS-compliant. |  |  |  |  |  |  |  |  | Voltage Detector with Adjustable Delay Time: CMOS processes are utilized to develop high precision | low current consumption CMOS reset ICs that allow arbitrary setting of the delay time. The extensive lineup includes both Nch Open Drain and CMOS output types in a wide range of detection voltages (from 2.3V to 6.0V | in 0.1V steps) | enabling selection of the ideal solution based on customer requirements. In addition | the entire series is of course both lead-free and RoHS-compliant. |  |  | 1.25mm |  |  | ROHM Semiconductor | BD5229G-TR |  |  | 755-BD5229G-TR | https://www.mouser.co.uk/ProductDetail/ROHM-Semiconductor/BD5229G-TR?qs=4kLU8WoGk0vvnhrrYwdszw%3D%3D
J1 | 112A-TAAR-R03_ATTEND | 112A-TAAR-R03_ATTEND | 112ATAARR03ATTEND | Micro SD Card Socket, Push-Push Type, Top Mount, SMT, H=1.83mm, 10u |  |  |  |  |  |  |  |  | Micro SD Card Socket | Push-Push Type | Top Mount | SMT | H=1.83mm | 10u |  |  | 1.9mm |  |  | ATTEND | 112A-TAAR-R03 ATTEND
J2 | QWIIC_RIGHT_ANGLE | QWIIC_CONNECTORJS-1MM | JST04_1MM_RA | SparkFun I2C Standard Qwiic Connector |  |  |  |  |  |  |  |  |  |  |  |  |  |  |  |  |  |  |  |  |  |  |  |  |  |  |  |  |  |  |  |  | CONN-13694 |  |  |  |  |  |  |  |  |  |  |  |  |  |  | QWIIC_RIGHT_ANGLE
J3 | FH34SRJ-24S-0.5SH_99_ | FH34SRJ-24S-0.5SH_99_ | FH34SRJ24S05SH99 | (0.50mm) Surface Mount, Right Angle |  |  |  |  |  |  |  |  | 24 Position FFC | FPC Connector Contacts | (0.50mm) Surface Mount | Right Angle |  |  | 1.1mm |  |  | Hirose | FH34SRJ-24S-0.5SH(99) |  |  | 798-FH34SRJ24S05SH99 | https://www.mouser.co.uk/ProductDetail/Hirose-Connector/FH34SRJ-24S-0.5SH99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
J4 | SAMACSYS_PARTS_USB4110-GF-A | SAMACSYS_PARTS_USB4110-GF-A | SAMACSYS_PARTS_USB4110GFA | CONN USB 2.0 TYPE-C R/A SMT |  |  |  |  |  |  |  |  | CONN USB 2.0 TYPE-C R/A SMT |  |  | 3.26mm |  |  | GCT (GLOBAL CONNECTOR TECHNOLOGY) | USB4110-GF-A |  |  | 640-USB4110-GF-A | https://www.mouser.co.uk/ProductDetail/GCT/USB4110-GF-A?qs=KUoIvG%2F9IlYiZvIXQjyJeA%3D%3D
L1 | 744043680IND_4828-WE-TPC_WRE | 744043680IND_4828-WE-TPC_WRE | IND_4828-WE-TPC_WRE |  |  |  |  |  |  |  | Copyright (C) 2024 Ultra Librarian. All rights reserved. |  |  |  |  |  |  |  |  | 744043680 |  | Wurth Electronics
MCP73831 | ESP32_WROVER_SPARKFUN-IC-POWER_MCP73831 | ESP32_WROVER_SPARKFUN-IC-POWER_MCP73831 | ESP32_WROVER_SPARKFUN-IC-POWER_SOT23-5 | MCP73831T Li-Ion, Li-Pol Controller |  |  |  |  |  |  |  |  |  |  |  |  |  |  |  |  |  |  |  |  |  |  |  |  |  |  |  |  |  |  |  |  | IC-09995
Q1 | 20V/4.2A/52mO/1.4W | ESP32_WROVER_SPARKFUN-DISCRETESEMI_MOSFET_PCH-DMG2305UX-7 | ESP32_WROVER_SPARKFUN-DISCRETESEMI_SOT23-3 | P-channel MOSFETs |  |  |  |  |  |  |  |  |  |  |  |  |  |  |  |  |  |  |  |  |  |  |  |  |  |  |  |  |  |  |  |  | TRAN-14388 |  |  |  |  |  |  |  |  |  |  |  |  |  |  | 20V/4.2A/52mO/1.4W
Q2 | SI1308EDL-T1-GE3 | SI1308EDL-T1-GE3 | SOT65P210X110-3N | MOSFET N-Ch 30V 1.5A TrenchFET SC70 Vishay Si1308EDL-T1-GE3 N-channel MOSFET Transistor, 1.5 A, 30 V, 3-Pin SC-70 |  |  | In Stock |  |  | https://www.snapeda.com/parts/SI1308EDL-T1-GE3/Vishay+Siliconix/view-part/?ref=eda |  |  | Si1308EDL-T1-GE3 N-channel MOSFET Transistor | 1.5 A | 30 V | 3-Pin SC-70 | Siliconix / Vishay SI1308EDL-T1-GE3 |  |  |  |  |  |  |  | Vishay Siliconix |  |  |  |  |  | SI1308EDL-T1-GE3 |  |  | SOT-323 Vishay Semiconductor |  |  |  |  |  | None |  | https://www.snapeda.com/api/url_track_click_mouser/?unipart_id=274603&manufacturer=Vishay Siliconix&part_name=SI1308EDL-T1-GE3&search_term=None |  |  | https://www.snapeda.com/parts/SI1308EDL-T1-GE3/Vishay+Siliconix/view-part/?ref=snap
Q3 | 20V/4.2A/52mO/1.4W | ESP32_WROVER_SPARKFUN-DISCRETESEMI_MOSFET_PCH-DMG2305UX-7 | ESP32_WROVER_SPARKFUN-DISCRETESEMI_SOT23-3 | P-channel MOSFETs |  |  |  |  |  |  |  |  |  |  |  |  |  |  |  |  |  |  |  |  |  |  |  |  |  |  |  |  |  |  |  |  | TRAN-14388 |  |  |  |  |  |  |  |  |  |  |  |  |  |  | 20V/4.2A/52mO/1.4W
R1 |  | ESP32_WROVER_EAGLE-LTSPICE_RR0402 | ESP32_WROVER_EAGLE-LTSPICE_R0402 | RESISTOR, European symbol |  |  |  |  |  |  |  |  |  |  |  |  |  |  |  |  |  |  |  |  |  |  |  |  |  |  |  |  |  |  |  |  |  |  |  |  |  | NONE | R
R1_BAT | 200 | ESP32_WROVER_EAGLE-LTSPICE_RR0402 | ESP32_WROVER_EAGLE-LTSPICE_R0402 | RESISTOR, European symbol |  |  |  |  |  |  |  |  |  |  |  |  |  |  |  |  |  |  |  |  |  |  |  |  |  |  |  |  |  |  |  |  |  |  |  |  |  | NONE | R
R1_PWRUSB | 100K | ESP32_WROVER_EAGLE-LTSPICE_RR0402 | ESP32_WROVER_EAGLE-LTSPICE_R0402 | RESISTOR, European symbol |  |  |  |  |  |  |  |  |  |  |  |  |  |  |  |  |  |  |  |  |  |  |  |  |  |  |  |  |  |  |  |  |  |  |  |  |  | NONE | R
R2 | 2.2 | R_CHIP-0402(1005-METRIC) | RESC1005X40 | Resistor Fixed - Generic |  |  |  | Resistors |  |  |  |  | Chip Resistor 1.05 X 0.54 X 0.40 mm body 0402(1005-METRIC) Package |  |  |  |  |  |  |  |  |  |  |  |  |  |  |  |  |  | 0402 | SMD
R2_BAT | 2K | ESP32_WROVER_EAGLE-LTSPICE_RR0402 | ESP32_WROVER_EAGLE-LTSPICE_R0402 | RESISTOR, European symbol |  |  |  |  |  |  |  |  |  |  |  |  |  |  |  |  |  |  |  |  |  |  |  |  |  |  |  |  |  |  |  |  |  |  |  |  |  | NONE | R
R3 |  | ESP32_WROVER_EAGLE-LTSPICE_RR0402 | ESP32_WROVER_EAGLE-LTSPICE_R0402 | RESISTOR, European symbol |  |  |  |  |  |  |  |  |  |  |  |  |  |  |  |  |  |  |  |  |  |  |  |  |  |  |  |  |  |  |  |  |  |  |  |  |  | NONE | R
R4 |  | ESP32_WROVER_EAGLE-LTSPICE_RR0402 | ESP32_WROVER_EAGLE-LTSPICE_R0402 | RESISTOR, European symbol |  |  |  |  |  |  |  |  |  |  |  |  |  |  |  |  |  |  |  |  |  |  |  |  |  |  |  |  |  |  |  |  |  |  |  |  |  | NONE | R
R5 | 10K | ESP32_WROVER_EAGLE-LTSPICE_RR0402 | ESP32_WROVER_EAGLE-LTSPICE_R0402 | RESISTOR, European symbol |  |  |  |  |  |  |  |  |  |  |  |  |  |  |  |  |  |  |  |  |  |  |  |  |  |  |  |  |  |  |  |  |  |  |  |  |  | NONE | R
R6 | 0.47 | ESP32_WROVER_EAGLE-LTSPICE_RR0402 | ESP32_WROVER_EAGLE-LTSPICE_R0402 | RESISTOR, European symbol |  |  |  |  |  |  |  |  |  |  |  |  |  |  |  |  |  |  |  |  |  |  |  |  |  |  |  |  |  |  |  |  |  |  |  |  |  | NONE | R
R7 | 10K | ESP32_WROVER_EAGLE-LTSPICE_RR0402 | ESP32_WROVER_EAGLE-LTSPICE_R0402 | RESISTOR, European symbol |  |  |  |  |  |  |  |  |  |  |  |  |  |  |  |  |  |  |  |  |  |  |  |  |  |  |  |  |  |  |  |  |  |  |  |  |  | NONE | R
R8 | 10K | ESP32_WROVER_EAGLE-LTSPICE_RR0402 | ESP32_WROVER_EAGLE-LTSPICE_R0402 | RESISTOR, European symbol |  |  |  |  |  |  |  |  |  |  |  |  |  |  |  |  |  |  |  |  |  |  |  |  |  |  |  |  |  |  |  |  |  |  |  |  |  | NONE | R
R9 | 10K | ESP32_WROVER_EAGLE-LTSPICE_RR0402 | ESP32_WROVER_EAGLE-LTSPICE_R0402 | RESISTOR, European symbol |  |  |  |  |  |  |  |  |  |  |  |  |  |  |  |  |  |  |  |  |  |  |  |  |  |  |  |  |  |  |  |  |  |  |  |  |  | NONE | R
R10 | 10K | ESP32_WROVER_EAGLE-LTSPICE_RR0402 | ESP32_WROVER_EAGLE-LTSPICE_R0402 | RESISTOR, European symbol |  |  |  |  |  |  |  |  |  |  |  |  |  |  |  |  |  |  |  |  |  |  |  |  |  |  |  |  |  |  |  |  |  |  |  |  |  | NONE | R
R11 | 10K | ESP32_WROVER_EAGLE-LTSPICE_RR0402 | ESP32_WROVER_EAGLE-LTSPICE_R0402 | RESISTOR, European symbol |  |  |  |  |  |  |  |  |  |  |  |  |  |  |  |  |  |  |  |  |  |  |  |  |  |  |  |  |  |  |  |  |  |  |  |  |  | NONE | R
R12 | 10K | ESP32_WROVER_EAGLE-LTSPICE_RR0402 | ESP32_WROVER_EAGLE-LTSPICE_R0402 | RESISTOR, European symbol |  |  |  |  |  |  |  |  |  |  |  |  |  |  |  |  |  |  |  |  |  |  |  |  |  |  |  |  |  |  |  |  |  |  |  |  |  | NONE | R
R13 |  | ESP32_WROVER_EAGLE-LTSPICE_RR0402 | ESP32_WROVER_EAGLE-LTSPICE_R0402 | RESISTOR, European symbol |  |  |  |  |  |  |  |  |  |  |  |  |  |  |  |  |  |  |  |  |  |  |  |  |  |  |  |  |  |  |  |  |  |  |  |  |  | NONE | R
R14 |  | ESP32_WROVER_EAGLE-LTSPICE_RR0402 | ESP32_WROVER_EAGLE-LTSPICE_R0402 | RESISTOR, European symbol |  |  |  |  |  |  |  |  |  |  |  |  |  |  |  |  |  |  |  |  |  |  |  |  |  |  |  |  |  |  |  |  |  |  |  |  |  | NONE | R
R15 |  | ESP32_WROVER_EAGLE-LTSPICE_RR0402 | ESP32_WROVER_EAGLE-LTSPICE_R0402 | RESISTOR, European symbol |  |  |  |  |  |  |  |  |  |  |  |  |  |  |  |  |  |  |  |  |  |  |  |  |  |  |  |  |  |  |  |  |  |  |  |  |  | NONE | R
R16 | 5k1 | ESP32_WROVER_EAGLE-LTSPICE_RR0402 | ESP32_WROVER_EAGLE-LTSPICE_R0402 | RESISTOR, European symbol |  |  |  |  |  |  |  |  |  |  |  |  |  |  |  |  |  |  |  |  |  |  |  |  |  |  |  |  |  |  |  |  |  |  |  |  |  | NONE | R
R17 | 5k1 | ESP32_WROVER_EAGLE-LTSPICE_RR0402 | ESP32_WROVER_EAGLE-LTSPICE_R0402 | RESISTOR, European symbol |  |  |  |  |  |  |  |  |  |  |  |  |  |  |  |  |  |  |  |  |  |  |  |  |  |  |  |  |  |  |  |  |  |  |  |  |  | NONE | R
R18 | ESP32C6_VARISTORCN1812 | ESP32C6_VARISTORCN1812 | ESP32C6_VARISTOR_CT/CN1812 | VARISTOR |  |  |  |  |  |  |  |  |  |  |  |  |  |  |  |  |  |  |  |  |  |  |  |  |  |  |  |  |  | 0
R19 | 10K | ESP32_WROVER_EAGLE-LTSPICE_RR0402 | ESP32_WROVER_EAGLE-LTSPICE_R0402 | RESISTOR, European symbol |  |  |  |  |  |  |  |  |  |  |  |  |  |  |  |  |  |  |  |  |  |  |  |  |  |  |  |  |  |  |  |  |  |  |  |  |  | NONE | R
R20 | 10K | ESP32_WROVER_EAGLE-LTSPICE_RR0402 | ESP32_WROVER_EAGLE-LTSPICE_R0402 | RESISTOR, European symbol |  |  |  |  |  |  |  |  |  |  |  |  |  |  |  |  |  |  |  |  |  |  |  |  |  |  |  |  |  |  |  |  |  |  |  |  |  | NONE | R
R21 | 10K | ESP32_WROVER_EAGLE-LTSPICE_RR0402 | ESP32_WROVER_EAGLE-LTSPICE_R0402 | RESISTOR, European symbol |  |  |  |  |  |  |  |  |  |  |  |  |  |  |  |  |  |  |  |  |  |  |  |  |  |  |  |  |  |  |  |  |  |  |  |  |  | NONE | R
R_CL1 | 10K | ESP32_WROVER_EAGLE-LTSPICE_RR0402 | ESP32_WROVER_EAGLE-LTSPICE_R0402 | RESISTOR, European symbol |  |  |  |  |  |  |  |  |  |  |  |  |  |  |  |  |  |  |  |  |  |  |  |  |  |  |  |  |  |  |  |  |  |  |  |  |  | NONE | R
SJ1 |  | SJ | SJ | SMD solder JUMPER |  |  |  |  |  |  |  |  |  |  |  |  |  |  |  |  |  |  |  |  |  |  |  |  |  |  |  |  |  | 33
TP1 | TPTP20R | TPTP20R | TP20R | Test pad |  |  |  |  |  |  |  |  |  |  |  |  |  |  |  |  |  |  |  |  |  |  |  |  |  |  |  |  |  | 2
TP2 | TPTP20R | TPTP20R | TP20R | Test pad |  |  |  |  |  |  |  |  |  |  |  |  |  |  |  |  |  |  |  |  |  |  |  |  |  |  |  |  |  | 2
TP3 | TPTP20R | TPTP20R | TP20R | Test pad |  |  |  |  |  |  |  |  |  |  |  |  |  |  |  |  |  |  |  |  |  |  |  |  |  |  |  |  |  | 2
TP4 | TPTP20R | TPTP20R | TP20R | Test pad |  |  |  |  |  |  |  |  |  |  |  |  |  |  |  |  |  |  |  |  |  |  |  |  |  |  |  |  |  | 2
TP5 | TPTP20R | TPTP20R | TP20R | Test pad |  |  |  |  |  |  |  |  |  |  |  |  |  |  |  |  |  |  |  |  |  |  |  |  |  |  |  |  |  | 2
TP6 | TPTP20R | TPTP20R | TP20R | Test pad |  |  |  |  |  |  |  |  |  |  |  |  |  |  |  |  |  |  |  |  |  |  |  |  |  |  |  |  |  | 2
TP7 | TPTP20R | TPTP20R | TP20R | Test pad |  |  |  |  |  |  |  |  |  |  |  |  |  |  |  |  |  |  |  |  |  |  |  |  |  |  |  |  |  | 2
TP8 | TPTP20R | TPTP20R | TP20R | Test pad |  |  |  |  |  |  |  |  |  |  |  |  |  |  |  |  |  |  |  |  |  |  |  |  |  |  |  |  |  | 2
TP9 | TPTP20R | TPTP20R | TP20R | Test pad |  |  |  |  |  |  |  |  |  |  |  |  |  |  |  |  |  |  |  |  |  |  |  |  |  |  |  |  |  | 2
TP10 | TPTP20R | TPTP20R | TP20R | Test pad |  |  |  |  |  |  |  |  |  |  |  |  |  |  |  |  |  |  |  |  |  |  |  |  |  |  |  |  |  | 2
TP11 | TPTP20R | TPTP20R | TP20R | Test pad |  |  |  |  |  |  |  |  |  |  |  |  |  |  |  |  |  |  |  |  |  |  |  |  |  |  |  |  |  | 2
TP12 | TPTP20R | TPTP20R | TP20R | Test pad |  |  |  |  |  |  |  |  |  |  |  |  |  |  |  |  |  |  |  |  |  |  |  |  |  |  |  |  |  | 2
TP13 | TPTP20R | TPTP20R | TP20R | Test pad |  |  |  |  |  |  |  |  |  |  |  |  |  |  |  |  |  |  |  |  |  |  |  |  |  |  |  |  |  | 2
TP14 | TPTP20R | TPTP20R | TP20R | Test pad |  |  |  |  |  |  |  |  |  |  |  |  |  |  |  |  |  |  |  |  |  |  |  |  |  |  |  |  |  | 2
TP15 | TPTP20R | TPTP20R | TP20R | Test pad |  |  |  |  |  |  |  |  |  |  |  |  |  |  |  |  |  |  |  |  |  |  |  |  |  |  |  |  |  | 2
TP16 | TPTP20R | TPTP20R | TP20R | Test pad |  |  |  |  |  |  |  |  |  |  |  |  |  |  |  |  |  |  |  |  |  |  |  |  |  |  |  |  |  | 2
TP17 | TPTP20R | TPTP20R | TP20R | Test pad |  |  |  |  |  |  |  |  |  |  |  |  |  |  |  |  |  |  |  |  |  |  |  |  |  |  |  |  |  | 2
U$1 | BUTTON_CUSYOMV1 | BUTTON_CUSYOMV1 | MYBUTTON
U$2 | BUTTON_CUSYOMV1 | BUTTON_CUSYOMV1 | MYBUTTON
U$3 | BUTTON_CUSYOMV1 | BUTTON_CUSYOMV1 | MYBUTTON
U1 | MAX17048G+T10 | MAX17048G+T10 | SON50P200X200X80-9N | Check availability |  |  | In Stock |  |  | https://www.snapeda.com/parts/MAX17048G+T10/Analog+Devices/view-part/?ref=eda |  |  | 3µA 1-Cell/2-Cell Fuel Gauge with ModelGauge |  |  |  |  |  |  |  | Analog Devices |  |  |  |  |  | MAX17048G+T10 |  |  | TDFN-8 Maxim |  |  |  |  |  | None |  | https://www.snapeda.com/api/url_track_click_mouser/?unipart_id=329239&manufacturer=Analog Devices&part_name=MAX17048G+T10&search_term=None |  |  | https://www.snapeda.com/parts/MAX17048G+T10/Analog+Devices/view-part/?ref=snap
U2 | W25Q512JVEIQ | W25Q512JVEIQ | SON127P600X800X80-9N | Check availability |  |  | In Stock |  |  | https://www.snapeda.com/parts/W25Q512JVEIQ/Winbond+Electronics/view-part/?ref=eda |  |  | FLASH - NOR Memory IC 512Mb (64M x 8) SPI - Quad I/O 133 MHz 8-WSON (8x6) |  |  |  |  |  |  |  | Winbond Electronics |  |  |  |  |  | W25Q512JVEIQ |  |  | Package |  |  |  |  |  | None |  |  |  |  | https://www.snapeda.com/parts/W25Q512JVEIQ/Winbond+Electronics/view-part/?ref=snap
U3 | ESP32-C6-WROOM-1-N8 | ESP32-C6-WROOM-1-N8 | XCVR_ESP32-C6-WROOM-1-N8 | Check availability |  |  | In Stock |  |  | https://www.snapeda.com/parts/ESP32-C6-WROOM-1-N8/Espressif+Systems/view-part/?ref=eda |  |  | Multiprotocol Modules ESP32-C6 module | Wi-Fi 6 in 2.4 GHz band | Bluetooth 5 | Zigbee 3.0 and Thread. ESP34-WROOM Compatible - ENGINEERING SAMPLE |  |  |  |  |  |  |  | Espressif Systems |  |  |  |  |  | ESP32-C6-WROOM-1-N8 |  |  | None |  |  |  |  |  | None |  |  |  |  | https://www.snapeda.com/parts/ESP32-C6-WROOM-1-N8/Espressif+Systems/view-part/?ref=snap
U4 | ESP32_WROVER_BME680_BME680 | ESP32_WROVER_BME680_BME680 | ESP32_WROVER_BME680_PSON80P300X300X100-8N | Integrated Environmental Unit |  |  | Unavailable |  |  |  |  |  | Integrated Environmental Unit |  |  |  |  |  |  |  | Bosch Sensortec |  |  |  |  |  | BME680 |  |  | LGA-8 Bosch Tools |  |  |  |  |  | None
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

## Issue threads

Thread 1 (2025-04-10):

[SCHEMATIC] Componentele nu sunt prezentate corespunzator

CarolLuca, 2025-04-10:
## Issue description
- componentele nu sunt aranjate intr-un mod clar si urmarirea lor poate deveni ingreunata

## Suggestions
- poti include frame-ul ce poarta numele `ESP32_WROVER_FRAMES_A3L-LOC` din libraria oferita in enunt (vezi imaginea atasata)
- poti pune text box-uri cu numele componentelor pentru a fi usor de identificat

## Attachments

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

shefancodeman, 2025-04-11:
Am adaugat nume deasupra fiecarui component si le-am separat mai bine, pentru a fi mai usor de diferentiat

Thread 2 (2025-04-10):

[PCB] Unghiuri drepte la rutare

CarolLuca, 2025-04-10:
## Issue description
- au mai ramas cateva unghiuri drepte nerezolvate

## Suggestion
- am observat ca majoritatea cazurilor de genul apar acolo unde 3 segmente se intersecteaza (vezi imaginea atasata)
- cel mai usor ar fi sa misti segmentul perpendicular pe celelalte doua

## Attachments

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

shefancodeman, 2025-04-11:
Am gasit 4 instanceuri de unghiuri drepte la intersectie. Am corectat si voi uploada versiunea noua, odata cu reformatarea repo-ului

Closed 2025-04-11.

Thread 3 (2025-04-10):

[PCB] Cateva dimensiuni putin diferite fata de requirements

CarolLuca, 2025-04-10:
## Issue description
- cateva dimensiuni off pe care si tu le-ai mentionat in README

## Suggestions
- cred ca ar fi de ajutor sa setezi grid size-ul la dimensiunea dorita si abia apoi sa faci measurements
- in anumite cazuri, e necesar sa fie un submultiplu al acestei dimensiuni, dar cu cat este mai mare, cu atat este mai usor

## Attachments

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

shefancodeman, 2025-04-11:
Diferentele sunt atat de mici ca le voi considera neglijabile

Closed 2025-04-11.

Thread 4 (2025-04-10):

[PCB] Cateva condensatoare de decuplare departate de pinii de alimentare

CarolLuca, 2025-04-10:
## Issue description
- cateva condensatoare sunt la limita respectarii acestei conditii: `Condensatoarele de decuplare (100nF) trebuie să fie amplasate cât mai aproape de pinii de alimentare ai diferitelor module și circuite integrate`

## Suggestions
- sa le muti mai aproape acolo unde sunt indepartate

## Attachments

DISCLAIMER: nu pot deschide schematic-ul asa cum scris si intr-un alt issue si e posibil ca aceasta imagine sa nu fie cea mai reprezentativa intrucat piesele nu par numite peste tot la fel ca in enunt

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

shefancodeman, 2025-04-11:
Am modificat tot pcb-ul si am amplasat anumite condensatoare mai aproape, cat de aproape imi permitea wiring-ul

Closed 2025-04-11.

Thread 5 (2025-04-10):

[3D] Nu se deschide produsul final

CarolLuca, 2025-04-10:
## Issue description
- `Error: New design cannot be created from a local file containing external references`

## Suggestion
- incearca sa mai descarci o data fisierele in cauza (precum `OpenBook Enclosure.f3d`), si sa verifici daca se pot deschide

## Attachments

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

shefancodeman, 2025-04-11:
Am reuploadat filele

Closed 2025-04-11.

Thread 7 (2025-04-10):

[DOCUMENTATION] Repo-ul nu respecta structura dorita

CarolLuca, 2025-04-10:
## Issue description
- fisierele nu sunt organizate dupa modelul din enunt:
```
- Hardware
  |-- fișierul schematic (.sch)
  |-- fișierul cu board-ul (.brd)
  - Manufacturing
  |-- gerbers.zip
  |-- fișierul Bill of Materials (.bom)
  |-- fișierul Pick and Place (.cpl)
  - Mechanical
  |-- fișierul 3D cu dispozitivul complet (PCB + baterie + display + carcasa) - exploded view (.step)
  |-- fișierul 3D Fusion360 cu dispozitivul complet
  - Images
  |-- imagini cu randări ale dispozitivului, plăcii etc.
  - LICENSE
  - README.md
```

## Suggestion
- acolo unde am mentionat ca exista probleme cu anumite fisiere, acestea trebuie refacute sau descarcate din nou
- este necesara asezarea lor in formatul de mai sus
- lipsesc complet imagini (screen print-uri mai exact)

Closed 2025-04-11.

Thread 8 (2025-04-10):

[ACCESS] Nu pot adauga labeluri pentru ca nu sunt colaborator la acest repo

CarolLuca, 2025-04-10:
## Issue description
- nu pot adauga labeluri la issue-urile anterioare pentru ca nu sunt contributor

## Suggestion
- adresa de email asociata contului de github este `gasancarolluca@gmail.com` iar numele de utilizator este `CarolLuca`
- poti urmari acest [tutorial](https://docs.github.com/en/account-and-profile/setting-up-and-managing-your-personal-account-on-github/managing-access-to-your-personal-repositories/inviting-collabo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)

Closed 2025-04-10.

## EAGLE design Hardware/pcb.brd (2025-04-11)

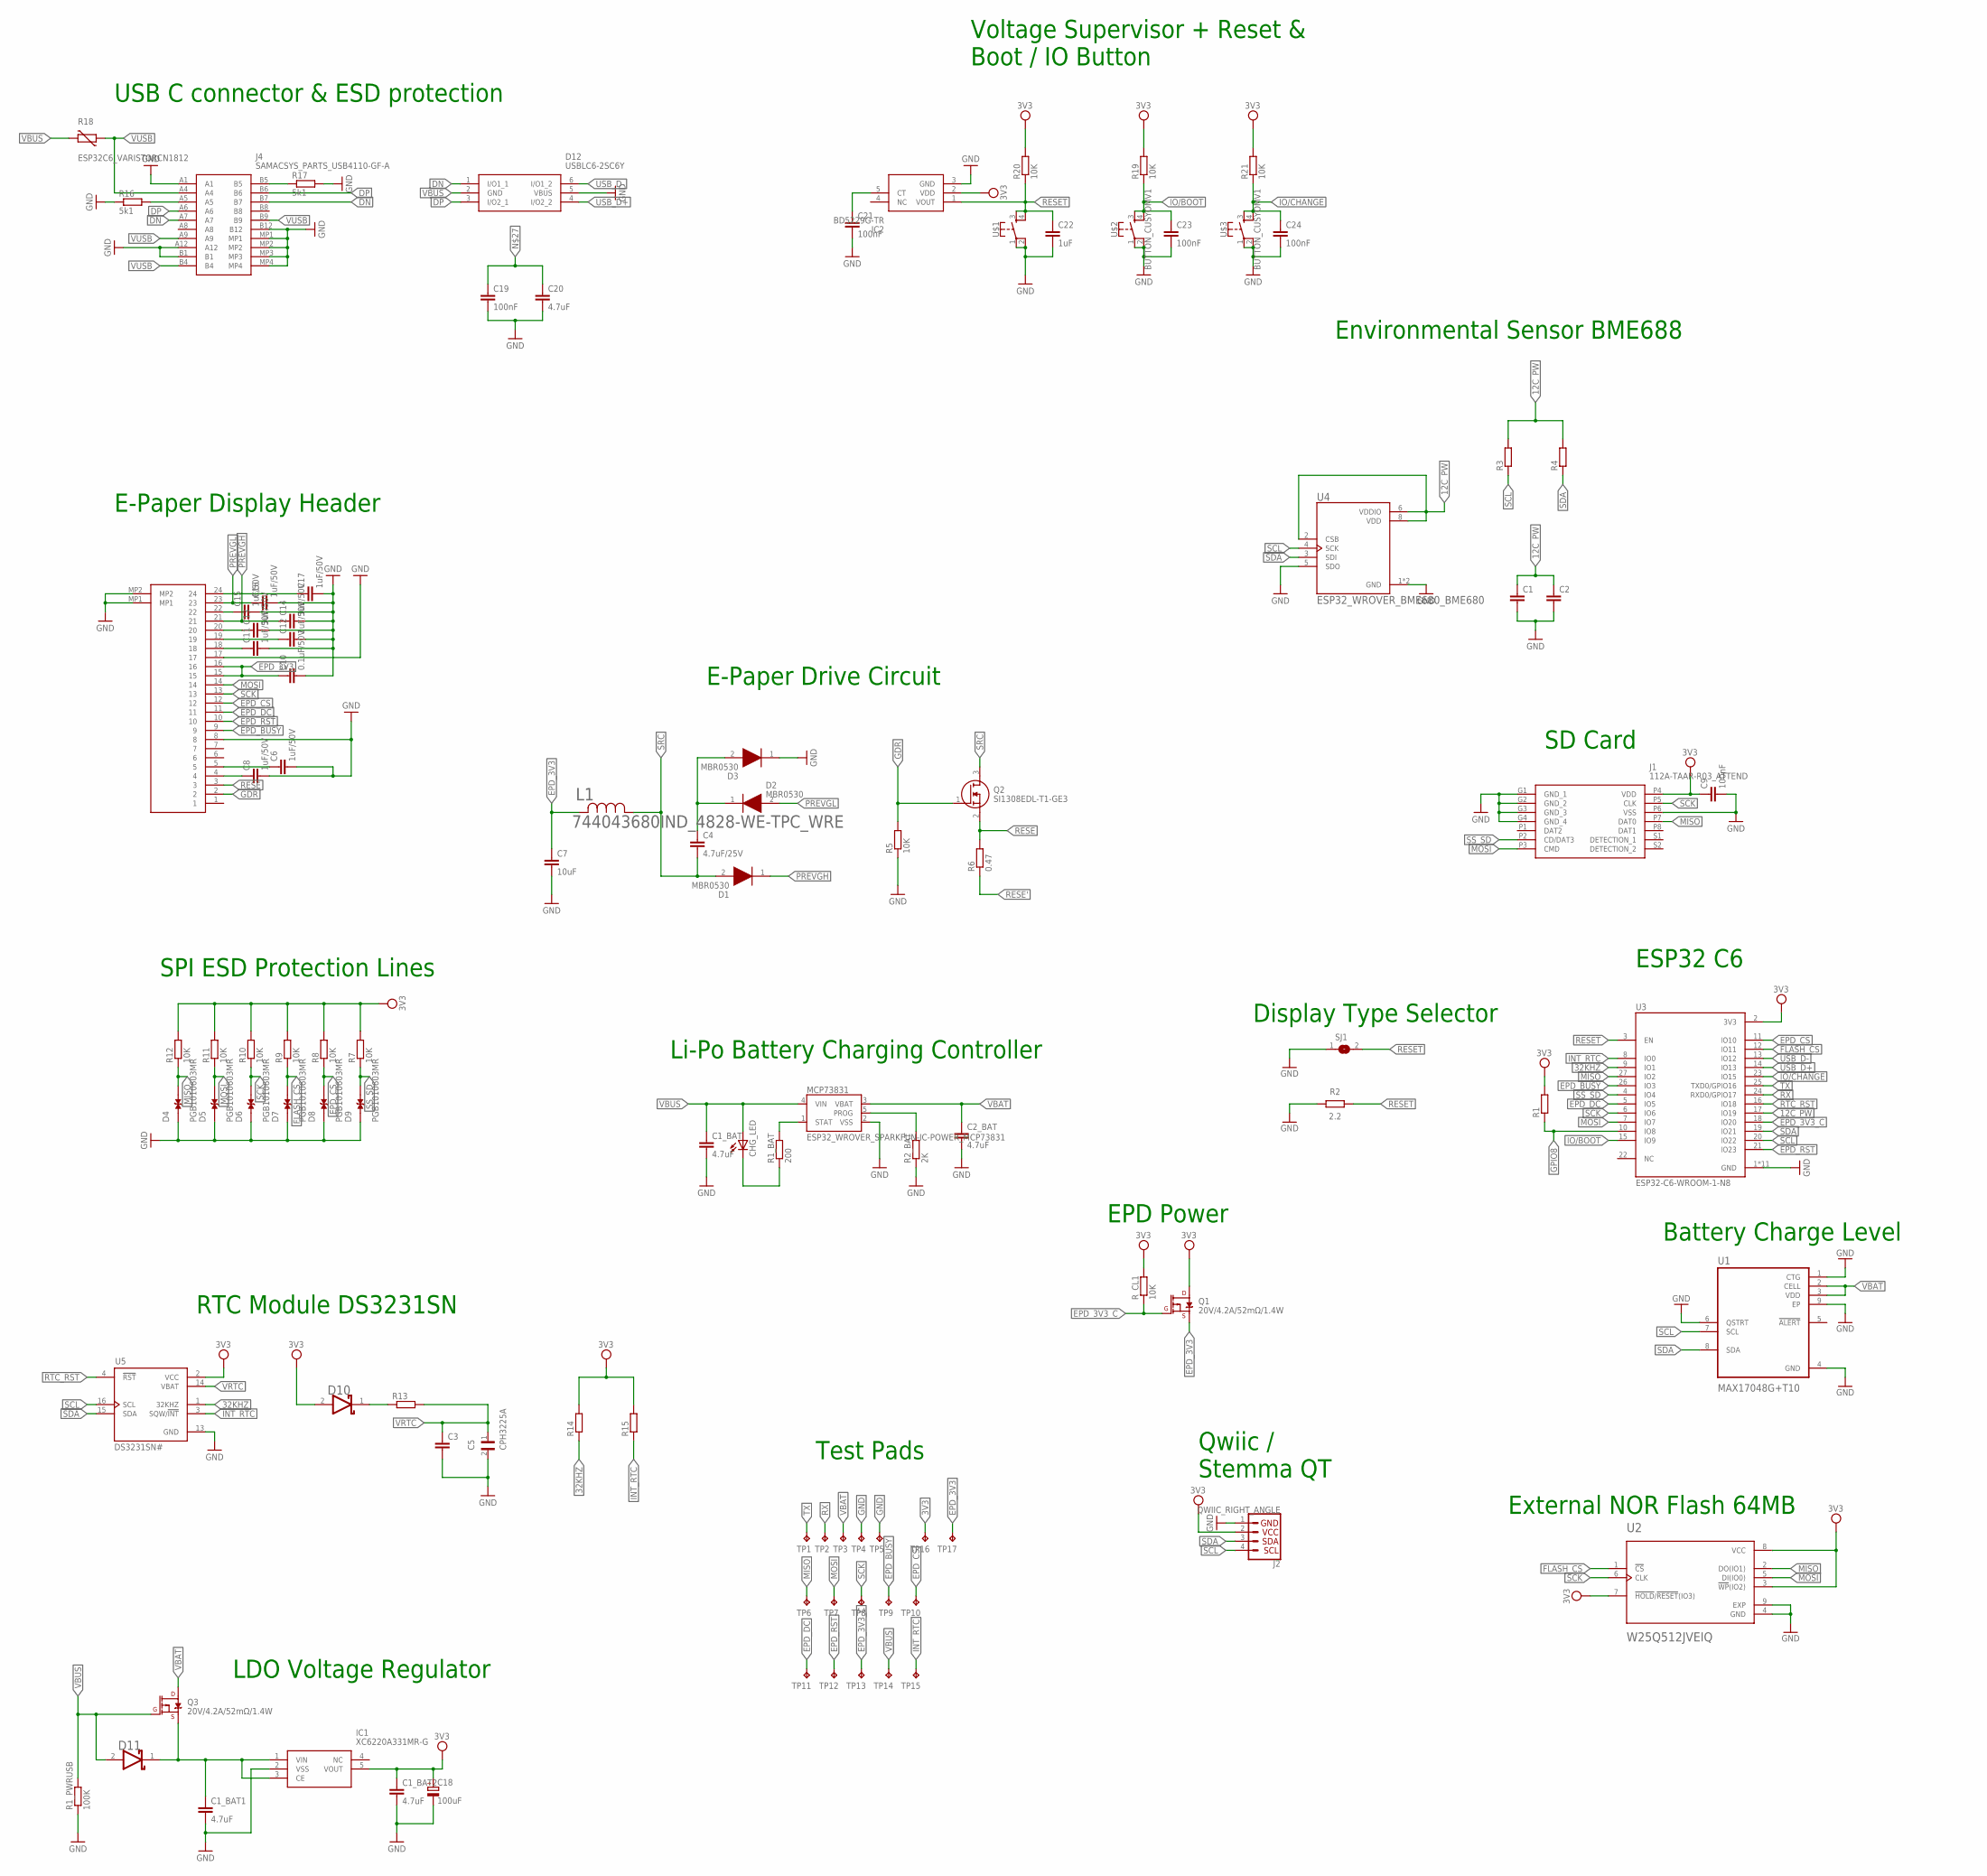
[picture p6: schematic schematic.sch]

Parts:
C1, C2: ESP32_WROVER_EAGLE-LTSPICE_CC0402; ESP32_WROVER_EAGLE-LTSPICE_C0402
C1_BAT, C1_BAT1, C1_BAT2, C2_BAT, C20: 4.7uF; ESP32_WROVER_EAGLE-LTSPICE_C0402
C3: EAGLE-LTSPICE_CC0402; EAGLE-LTSPICE_C0402
C4: 4.7uF/25V; EAGLE-LTSPICE_C0402
C5: CPH3225A; CAPCP3225X100N
C6, C8, C11, C12, C13, C14, C15, C16, C17: 1uF/50V; ESP32_WROVER_EAGLE-LTSPICE_C0402
C7: 10uF; EAGLE-LTSPICE_C0402
C9: 100nF; EAGLE-LTSPICE_C0402
C10: 0.1uF/50V; ESP32_WROVER_EAGLE-LTSPICE_C0402
C18: 100uF; RCL_CT3528
C19, C21, C23, C24: 100nF; ESP32_WROVER_EAGLE-LTSPICE_C0402
C22: 1uF; ESP32_WROVER_EAGLE-LTSPICE_C0402
CHG_LED: ADAFRUIT_LEDCHIP-LED0603; ADAFRUIT_CHIP-LED0603
D1, D2, D3: MBR0530; SOD3716X135N
D4, D5, D6, D7, D8, D9: PGB1010603MR; DIOC1608X36N
D10, D11: ESP32_WROVER_AVX---SD0805S020S1R0_AVX_SD0805S020S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; ESP32_WROVER_AVX---SD0805S020S1R0_AVX_SD0805S020S1R0_0
D12: USBLC6-2SC6Y; SOT95P280X145-6N
IC1: XC6220A331MR-G; SOT95P280X120-5N
IC2: BD5229G-TR; SOT95P280X125-5N
J1: 112A-TAAR-R03_ATTEND; 112ATAARR03ATTEND
J2: QWIIC_RIGHT_ANGLE; JST04_1MM_RA
J3: FH34SRJ-24S-0.5SH_99_; FH34SRJ24S05SH99
J4: SAMACSYS_PARTS_USB4110-GF-A; SAMACSYS_PARTS_USB4110GFA
L1: 744043680IND_4828-WE-TPC_WRE; IND_4828-WE-TPC_WRE
MCP73831: ESP32_WROVER_SPARKFUN-IC-POWER_MCP73831; ESP32_WROVER_SPARKFUN-IC-POWER_SOT23-5
Q1, Q3: 20V/4.2A/52mΩ/1.4W; ESP32_WROVER_SPARKFUN-DISCRETESEMI_SOT23-3
Q2: SI1308EDL-T1-GE3; SOT65P210X110-3N
R1, R3, R4, R13, R14, R15: ESP32_WROVER_EAGLE-LTSPICE_RR0402; ESP32_WROVER_EAGLE-LTSPICE_R0402
R1_BAT: 200; ESP32_WROVER_EAGLE-LTSPICE_R0402
R1_PWRUSB: 100K; ESP32_WROVER_EAGLE-LTSPICE_R0402
R2: 2.2; RESC1005X40
R2_BAT: 2K; ESP32_WROVER_EAGLE-LTSPICE_R0402
R5, R7, R8, R9, R10, R11, R12, R19, R20, R21: 10K; ESP32_WROVER_EAGLE-LTSPICE_R0402
R6: 0.47; ESP32_WROVER_EAGLE-LTSPICE_R0402
R16, R17: 5k1; ESP32_WROVER_EAGLE-LTSPICE_R0402
R18: ESP32C6_VARISTORCN1812; ESP32C6_VARISTOR_CT/CN1812
R_CL1: 10K; ESP32_WROVER_EAGLE-LTSPICE_R0402
SJ1: SJ
TP1, TP2, TP3, TP4, TP5, TP6, TP7, TP8, TP9, TP10, TP11, TP12, TP13, TP14, TP15, TP16, TP17: TPTP20R; TP20R
U1: MAX17048G+T10; SON50P200X200X80-9N
U2: W25Q512JVEIQ; SON127P600X800X80-9N
U3: ESP32-C6-WROOM-1-N8; XCVR_ESP32-C6-WROOM-1-N8
U4: ESP32_WROVER_BME680_BME680; ESP32_WROVER_BME680_PSON80P300X300X100-8N
U5: DS3231SN#; SOIC127P1032X265-16N
U$1, U$2, U$3: BUTTON_CUSYOMV1; MYBUTTON

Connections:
3V3: C1_BAT2.1, C9.1, C18.+, D10.2 (ANODE), IC1.5 (VOUT), IC2.2 (VDD), J1.P4 (VDD), J2.2, Q1.3 (D), R1.2, R7.2, R8.2, R9.2, R10.2, R11.2, R12.2, R14.2, R15.2, R19.2, R20.2, R21.2, R_CL1.2, TP16.TP, U2.3 (!WP!(IO2)), U2.7 (!HOLD!/!RESET!(IO3)), U2.8 (VCC), U3.2 (3V3), U5.2 (VCC)
12C_PW: C1.1, C2.1, R3.2, R4.2, U3.17 (IO19), U4.2 (CSB), U4.6 (VDDIO), U4.8 (VDD)
32KHZ: R14.1, U3.9 (IO1), U5.1 (32KHZ)
DN: D12.1 (I/O1_1), J4.A7, J4.B7
DP: D12.3 (I/O2_1), J4.A6, J4.B6
EPD_3V3: C7.1, C10.1, J3.15, J3.16, L1.2, Q1.2 (S), TP17.TP
EPD_3V3_C: Q1.1 (G), R_CL1.1, TP13.TP, U3.18 (IO20)
EPD_BUSY: J3.9, TP9.TP, U3.26 (IO3)
EPD_CS: D8.2, J3.12, R8.1, TP10.TP, U3.11 (IO10)
EPD_DC: J3.11, TP11.TP, U3.5 (IO5)
EPD_RST: J3.10, TP12.TP, U3.21 (IO23)
FLASH_CS: D7.2, R9.1, U2.1 (!CS), U3.12 (IO11)
GDR: J3.2, Q2.1 (G), R5.2
GND: C1.2, C1_BAT.2, C1_BAT1.2, C1_BAT2.2, C2.2, C2_BAT.2, C3.2, C5.2, C6.2, C7.2, C8.2, C9.2, C10.2, C11.2, C12.2, C13.2, C14.2, C15.2, C16.2, C17.2, C18.-, C19.2, C20.2, C21.2, C22.2, C23.2, C24.2, D3.1 (K), D4.1, D5.1, D6.1, D7.1, D8.1, D9.1, D12.5 (VBUS), IC1.2 (VSS), IC2.3 (GND), J1.G1 (GND_1), J1.G2 (GND_2), J1.G3 (GND_3), J1.G4 (GND_4), J1.P6 (VSS), J2.1, J3.8, J3.17, J3.MP1, J3.MP2, J4.A1, J4.A12, J4.B1, J4.B12, J4.MP1, J4.MP2, J4.MP3, J4.MP4, MCP73831.2 (VSS), R1_PWRUSB.1, R2.1, R2_BAT.1, R5.1, R16.1, R17.2, SJ1.1, TP4.TP, TP5.TP, U1.1 (CTG), U1.4 (GND), U1.6 (QSTRT), U1.9 (EP), U2.4 (GND), U2.9 (EXP), U3.1 (GND), U3.28 (GND), U3.29_1 (GND), U3.29_2 (GND), U3.29_3 (GND), U3.29_4 (GND), U3.29_5 (GND), U3.29_6 (GND), U3.29_7 (GND), U3.29_8 (GND), U3.29_9 (GND), U4.1 (GND), U4.5 (SDO), U4.7 (GND), U5.13 (GND), U$1.1, U$1.2, U$2.1, U$2.2, U$3.1, U$3.2
GPIO8: R1.1, U3.10 (IO8)
INT_RTC: R15.1, TP15.TP, U3.8 (IO0), U5.3 (SQW/!INT)
IO/BOOT: C23.1, R19.1, U3.15 (IO9), U$2.3, U$2.4
IO/CHANGE: C24.1, R21.1, U3.23 (IO15), U$3.3, U$3.4
MISO: D4.2, J1.P7 (DAT0), R12.1, TP6.TP, U2.2 (DO(IO1)), U3.27 (IO2)
MOSI: D5.2, J1.P3 (CMD), J3.14, R11.1, TP7.TP, U2.5 (DI(IO0)), U3.7 (IO7)
unnamed: C4.1, D2.1 (K), D3.2 (A)
unnamed: MCP73831.1 (STAT), R1_BAT.2
unnamed: CHG_LED.C, R1_BAT.1
unnamed: C1_BAT1.1, D11.1 (CATHODE), IC1.1 (VIN), IC1.3 (CE), Q3.2 (S)
unnamed: MCP73831.5 (PROG), R2_BAT.2
unnamed: C17.1, J3.24
unnamed: C21.1, IC2.5 (CT)
unnamed: C15.1, J3.22
unnamed: C13.1, J3.20
unnamed: D10.1 (CATHODE), R13.1
unnamed: C12.1, J3.19
unnamed: C11.1, J3.18
unnamed: C6.1, J3.5
unnamed: C8.1, J3.4
unnamed: J4.A5, R16.2
unnamed: C19.1, C20.1
unnamed: J4.B5, R17.1
PREVGH: C14.1, D1.1 (K), J3.21
PREVGL: C16.1, D2.2 (A), J3.23
RESE: J3.3, Q2.2 (S), R6.2
RESE': R6.1
RESET: C22.1, IC2.1 (VOUT), R2.2, R20.1, SJ1.2, U3.3 (EN), U$1.3, U$1.4
RTC_RST: U3.16 (IO18), U5.4 (!RST)
RX: TP2.TP, U3.24 (RXD0/GPIO17)
SCK: D6.2, J1.P5 (CLK), J3.13, R10.1, TP8.TP, U2.6 (CLK), U3.6 (IO6)
SCL: J2.4, R3.1, U1.7 (SCL), U3.20 (IO22), U4.4 (SCK), U5.16 (SCL)
SDA: J2.3, R4.1, U1.8 (SDA), U3.19 (IO21), U4.3 (SDI), U5.15 (SDA)
SRC: C4.2, D1.2 (A), L1.1, Q2.3 (D)
SS_SD: D9.2, J1.P2 (CD/DAT3), R7.1, U3.4 (IO4)
TX: TP1.TP, U3.25 (TXD0/GPIO16)
USB_D+: D12.4 (I/O2_2), U3.14 (IO13)
USB_D-: D12.6 (I/O1_2), U3.13 (IO12)
VBAT: C2_BAT.1, MCP73831.3 (VBAT), Q3.3 (D), TP3.TP, U1.2 (CELL), U1.3 (VDD)
VBUS: C1_BAT.1, CHG_LED.A, D11.2 (ANODE), D12.2 (GND), MCP73831.4 (VIN), Q3.1 (G), R1_PWRUSB.2, R18.2, TP14.TP
VRTC: C3.1, C5.1, R13.2, U5.14 (VBAT)
VUSB: J4.A4, J4.A9, J4.B4, J4.B9, R18.1

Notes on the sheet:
USB C connector & ESD protection
Voltage Supervisor + Reset & Boot / IO Button
Environmental Sensor BME688
SD Card
E-Paper Display Header
SPI ESD Protection Lines
E-Paper Drive Circuit
ESP32 C6
Battery Charge Level
External NOR Flash 64MB
Qwiic / Stemma QT
Li-Po Battery Charging Controller
Display Type Selector
EPD Power
Test Pads
RTC Module DS3231SN
LDO Voltage Regulator

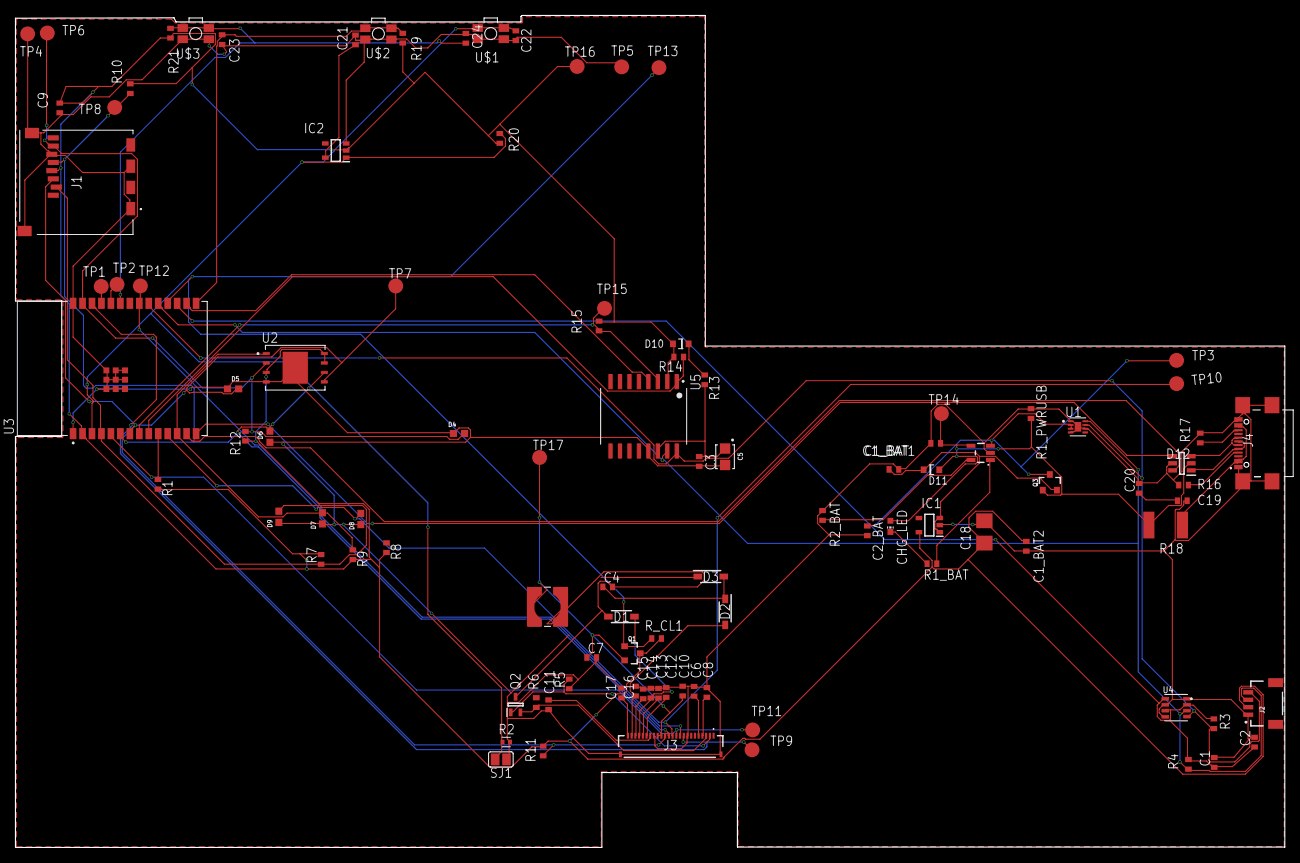
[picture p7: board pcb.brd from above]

Board: 2 copper layers, 170.4 x 111.7 mm, 103 parts (0 on the bottom side), 55 nets.

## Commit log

2025-03-22 All components done
    Recreated all components, now positioning and assembly is required
2025-03-25 Last changes regarding components, board changes
    Added last changes to components (not a lot, just moving around), board has been measured and is ready to cut. Placement is needed
2025-03-25 Delete EBook READER v4 - Board.fbrd
    Deleted old version
2025-03-25 Delete EBook READER v6 - components.fsch
    Deleted old version - remeasured and cut the pcb since
2025-03-30 Project almost ready, besides ReadMe
    Created the 3D files for battery and display and combined them into a full product
    [Bill of Materials.csv]
2025-03-30 Delete EBook READER v7 - PCB.fbrd
    Deleted old file
2025-03-30 Delete EBook READER v8 - schematic.fsch
    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
2025-04-03 3D models not permitted withou custom models
    I cannot upload 3D PCB model as FUSION doesn't allow bulk download of custom models. Without those models, the PCB cannot be uploaded
    [7.5inch e-Paper V2 v3.f3d, CELLEVIA BATTERIES LP584174 v1.f3d, PnP_EBook READER v14_front.csv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]
2025-04-03 The 3D file finally uploaded
    [OpenBook Enclosure.f3d]
2025-04-11 Deleted files
    Needed to clear out the repo in order to upload new files
    [PnP_EBook READER v14_front.csv]
2025-04-11 Deleted everything just to reupload
    Uploaded every file with the required formatting
    [PnP_EBook READER v18_front.csv, bom.csv, pcb.brd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]
2025-04-11 Am realizat ca nu am copiat repo-ul deloc
    Am aliniat butoanele, si am completat issue-urile
    [PnP_EBook READER v18_front.csv, PnP_EBook READER v23_front.csv, pcb.brd]

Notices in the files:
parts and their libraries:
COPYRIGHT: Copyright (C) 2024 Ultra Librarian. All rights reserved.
